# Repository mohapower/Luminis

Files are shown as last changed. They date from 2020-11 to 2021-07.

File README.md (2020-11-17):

# Luminis

**Fényerő kapcsolási határérték beállítása:**
1. Soros monitor megnyitása
  - Hardver csatlakoztatása usb kábbellel a számítógéphez
  - Arduino Ide megnyitása
  - Port beállítása: Menüsorvól: Eszközök/Port --> megfelelő port kiválasztása
  - Soros Monitor megnyitása: Eszközök/Soros monitor vagy Ctrl+Shift+M
  - Jobb alsó sarokban a "nincs sorvég" és "9600 baud" legyen beállítva
  - Ha minden működik, akkor a következő adatok jelennek meg másodpercenként:
    - Mert fenyero: 158
    - A beallitott kapcsolasi hatarartek: 333
    - Sotet van/Világos van
    
2. Fényerő kapcsolási határérték beállítása:
  - Bal felső beviteli mezőbe írjuk be az új kapcsolási határértéket, 0-1023 közötti értékek megfelelőek
  - Nomjuk meg a külség gombot (enter), a következő jelenik meg:
    - Az uj kapcsolasi hatarertek: 777
    - Mert fenyero: 232
    - A beallitott kapcsolasi hatarartek: 777
    - Sotet van

Amennyiben a mert fényerő alacsonyabb mit a beállított, az eszköt azt érzékeli, hogy sötét van. Vagyis ha a kapcsolási határértéket növeljük, a világítás előbb (nagyobb fénynél) fog kapcsolni.

**Firmware frissítés:**
Open your sketch
Open the IdoRele.ino

Select your board type and port
Select Tools > Board > Arduino AVR Boards > Arduino Nano.

NOTE: We have updated the Nano board with a fresh bootloader. 
Boards sold by us from January 2018 have this new bootloader, while boards manufactured before that date have the old bootloader. 
First, check that Tools > Board > Boards Manager shows you have the Arduino AVR Boards 1.16.21 or later installed. 
Then, to program the NEW Arduino NANO boards you need to chose Tools > Processor > ATmega328P. 
To program old boards you need to choose Tools > Processor > ATmega328P (Old Bootloader). 
If you get an error while uploading or you are not sure which bootloader you have, try each Tools > Processor menu option until your board gets properly programmed.

Upload and Run your first Sketch
To upload the sketch to the Arduino Nano, click the Upload button in the upper left to load and run the sketch on your board:

UNO Upload

Wait a few seconds - you should see the RX and TX LEDs on the board flashing. 
If the upload is successful, the message "Done uploading." will appear in the status bar.

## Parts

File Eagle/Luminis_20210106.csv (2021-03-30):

Qty | Value | Device | Package | Parts | Description | MF | MPN | OC_FARNELL | OC_NEWARK | SPICEPREFIX
1 |  | ARDUINO_NANO | ARDUINO_NANO | ARDUINO_NANO_V3 | Arduino Nano V3.0
1 | 100n | C-EUC1206 | C1206 | C2 | CAPACITOR, European symbol |  |  |  |  | C
1 | 330n | C-EUC1206 | C1206 | C1 | CAPACITOR, European symbol |  |  |  |  | C
1 | 7808DT | 7808DT | TO252 | IC1 | Positive VOLTAGE REGULATOR |  |  | DPAC
1 | ES1B | DIODE-DO214AC | DO214AC | D1 | DIODE |  |  | SMA
10 | MKDSN1,5/2-5,08 | MKDSN1,5/2-5,08 | MKDSN1,5/2-5,08 | IN, PWR, X1 | MKDSN 1,5/ 2-5,08 Printklemme
1 | SMBJ24CD-M3/H | SUPPRESSOR-SMBJ | SMBJ | D2 | Suppressor diode
1 | TR5, 0,5A | TR5 | TR5 | F1 | FUSE |  |  | unknown | unknown
1 | SEN0043 DFROBOT

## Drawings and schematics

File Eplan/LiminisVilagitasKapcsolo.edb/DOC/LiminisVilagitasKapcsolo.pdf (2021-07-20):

## Folyosó világítás működtető jel Másik Időrelétől (D7 pin)

-U3

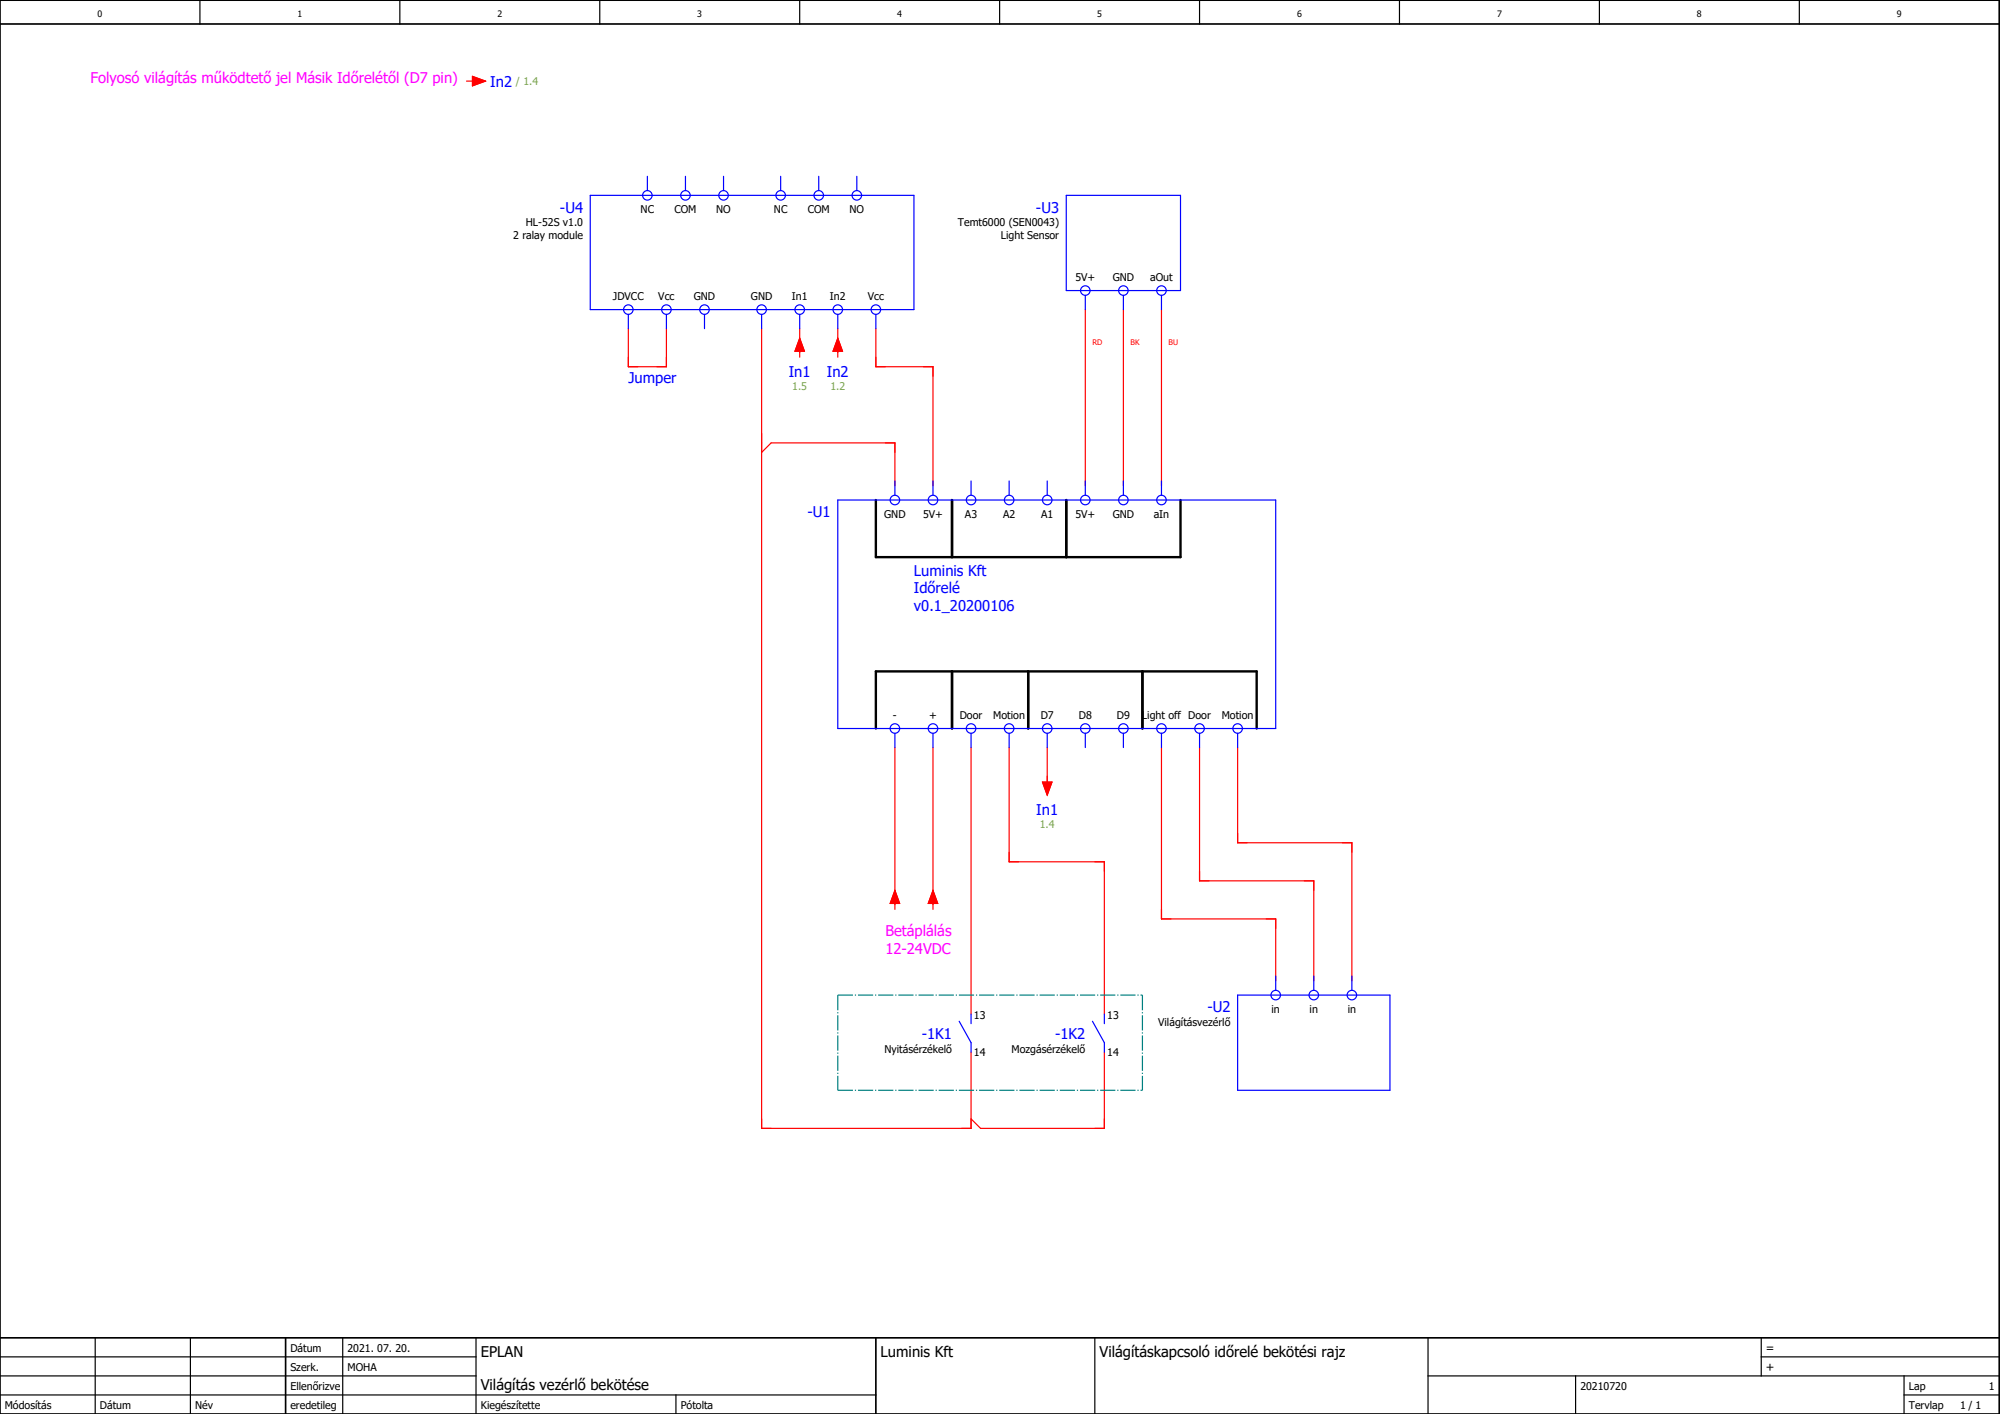
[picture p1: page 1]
Luminis Kft Időrelé v0.1_20200106; Jumper; Betáplálás 12-24VDC; GND; aIn; Door Motion; Light off Door Motion; Nyitásérzékelő; Mozgásérzékelő; Világításvezérlő; Temt6000 (SEN0043) Light Sensor; aOut; HL-52S v1.0 2 ralay module; JDVCC; Vcc; COM

Dátum | 2021. 07. 20. | EPLAN Világítás vezérlő bekötése | Luminis Kft | Világításkapcsoló időrelé bekötési rajz | =
Szerk. | MOHA | | | | +

Ellenőrizve | | | | | 20210720 | Lap 1

Módosítás | Dátum | Név | eredetileg | | Kiegészítette | Pótolta | | | | Tervlap 1 / 1

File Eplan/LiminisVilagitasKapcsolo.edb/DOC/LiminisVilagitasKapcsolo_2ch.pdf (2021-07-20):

-U3

-U4

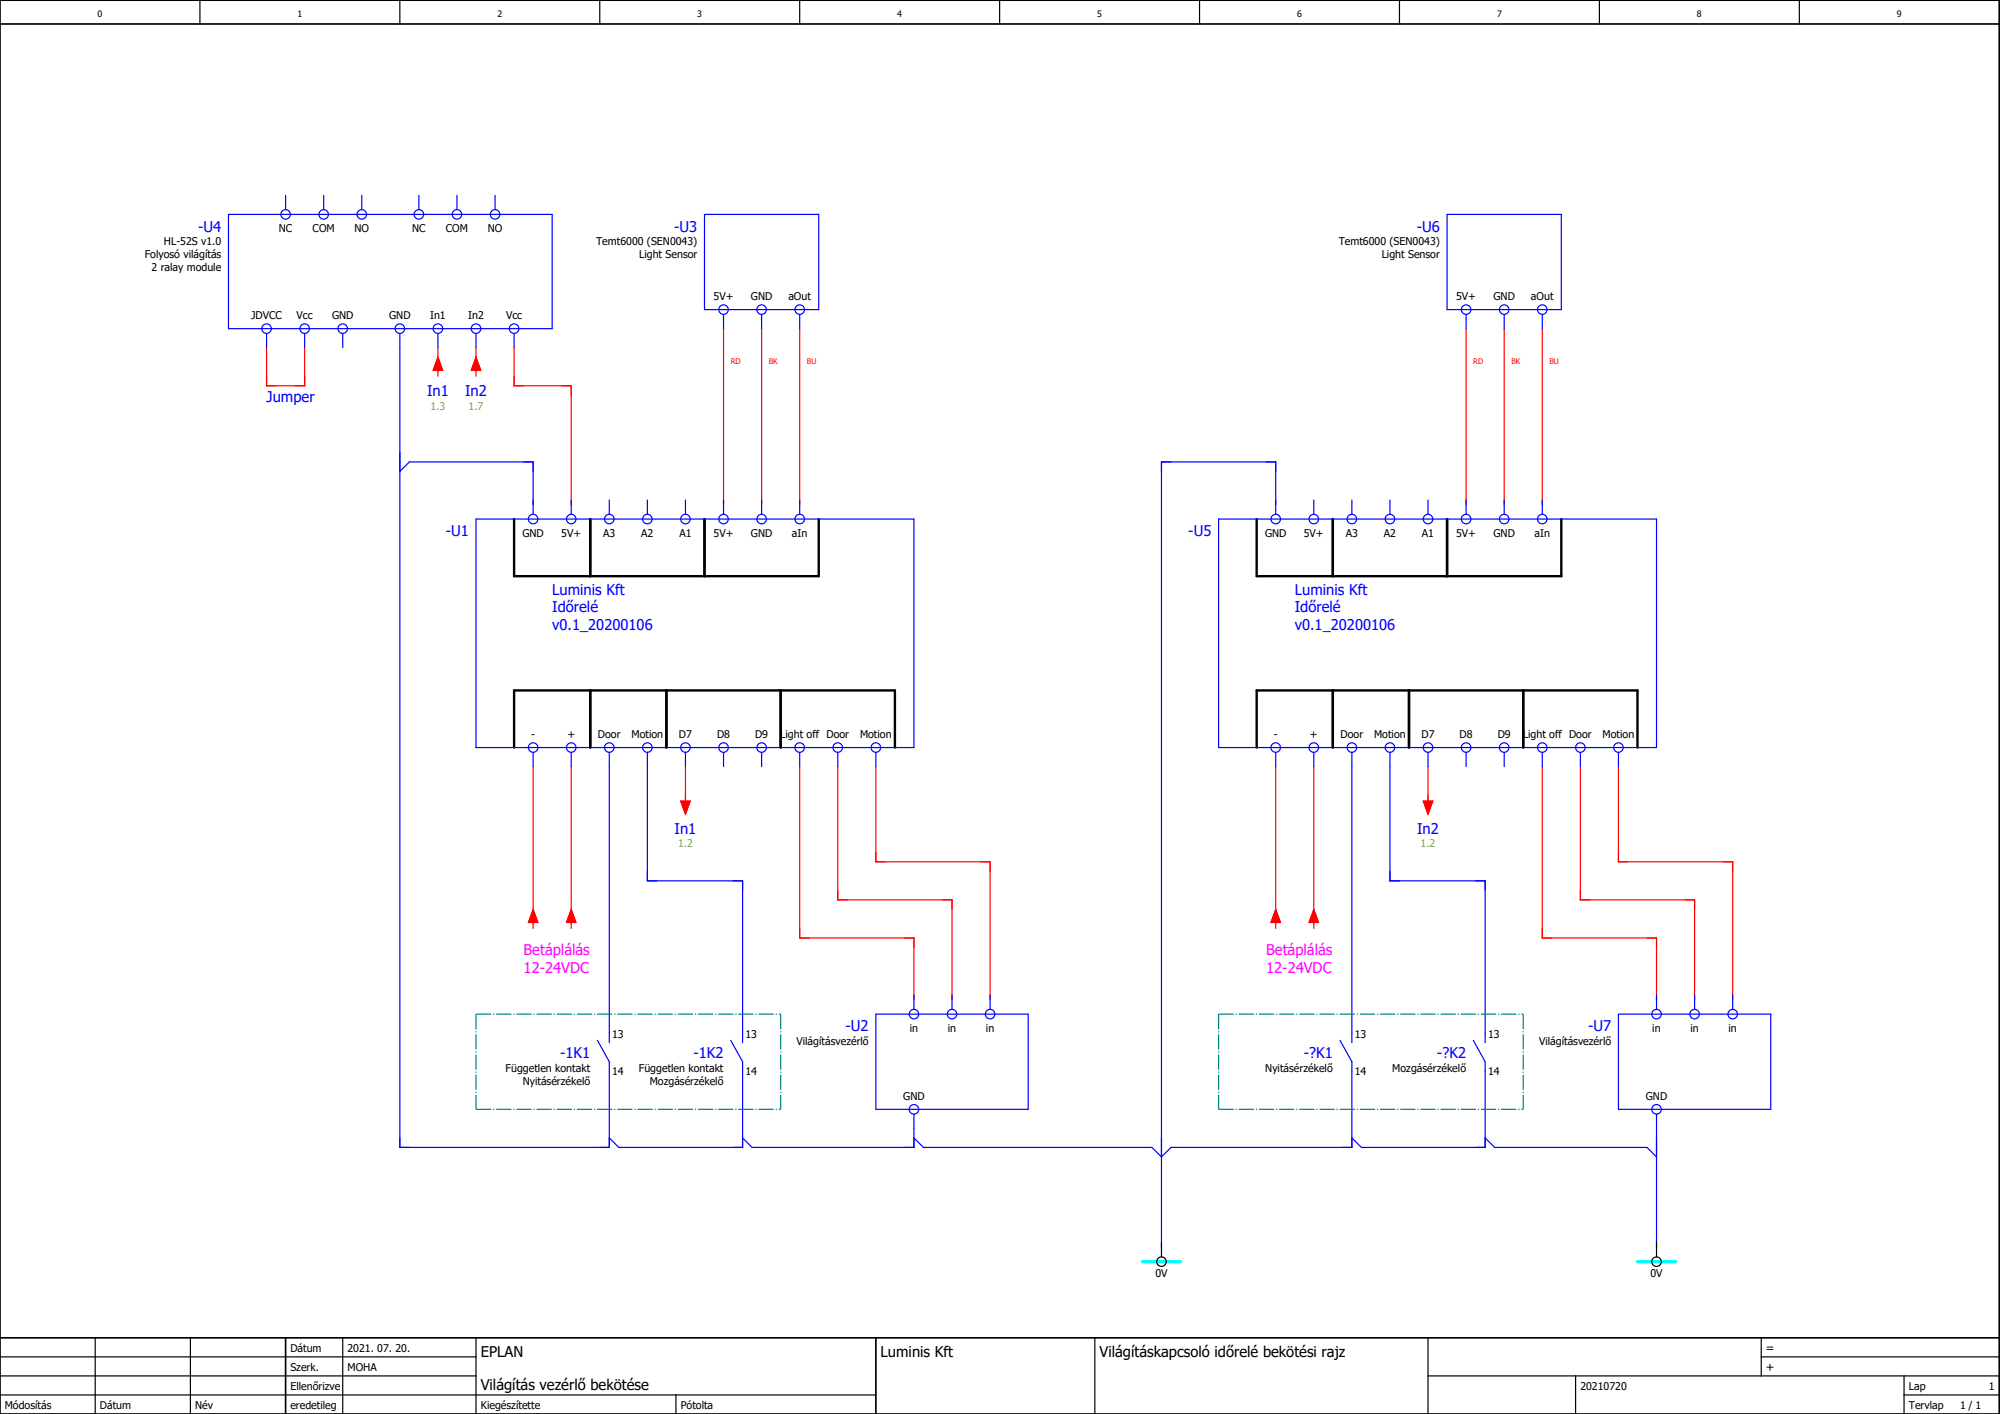
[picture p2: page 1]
Luminis Kft Időrelé v0.1_20200106; Jumper; Betáplálás 12-24VDC; GND; aIn; Door Motion; Light off Door Motion; Független kontakt Nyitásérzékelő; Független kontakt Mozgásérzékelő; Világításvezérlő; Temt6000 (SEN0043) Light Sensor; aOut; HL-52S v1.0 Folyosó világítás 2 ralay module; JDVCC; Vcc; COM; Nyitásérzékelő; Mozgásérzékelő

Dátum | 2021. 07. 20. | EPLAN Világítás vezérlő bekötése | Luminis Kft | Világításkapcsoló időrelé bekötési rajz | =
Szerk. | MOHA | | | | +

Ellenőrizve | | | | | 20210720 | Lap 1

Módosítás | Dátum | Név | eredetileg | | Kiegészítette | Pótolta | | | | Tervlap 1 / 1

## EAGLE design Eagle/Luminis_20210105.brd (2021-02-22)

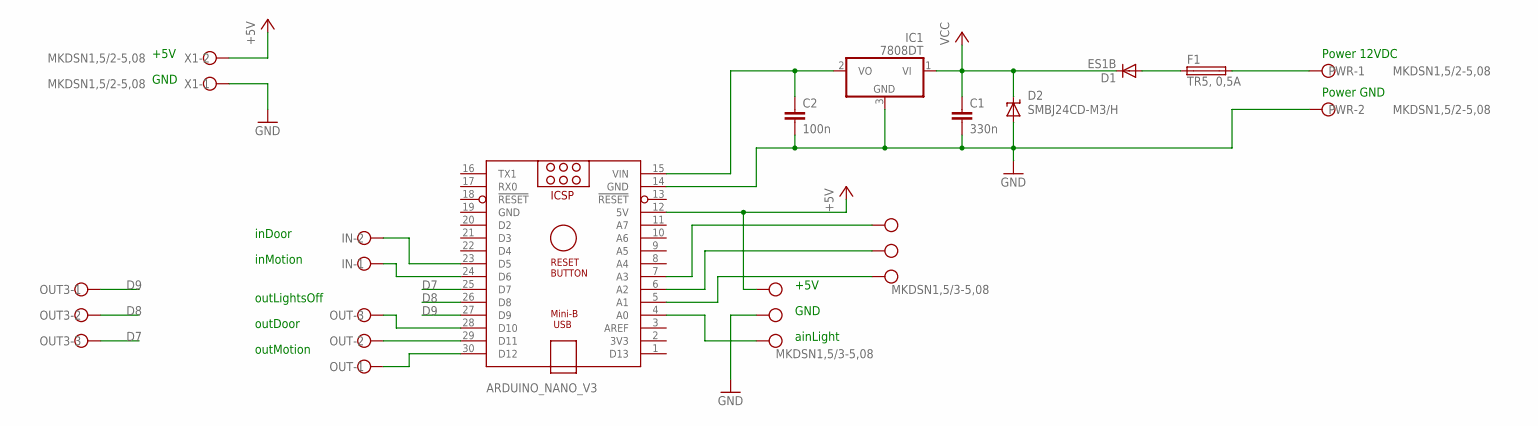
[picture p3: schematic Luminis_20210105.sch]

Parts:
ARDUINO_NANO_V3: ARDUINO_NANO
C1: 330n; C1206
C2: 100n; C1206
D1: ES1B; DO214AC
D2: SMBJ24CD-M3/H; SMBJ
F1: TR5, 0,5A; TR5
IC1: 7808DT; TO252
IN: MKDSN1,5/2-5,08
OUT, OUT1, OUT2, OUT3: MKDSN1,5/3-5,08
PWR: MKDSN1,5/2-5,08
X1: MKDSN1,5/2-5,08

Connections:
+5V: ARDUINO_NANO_V3.12 (5V), OUT1.1, X1.2
D7: ARDUINO_NANO_V3.25 (D7), OUT3.3
D8: ARDUINO_NANO_V3.26 (D8), OUT3.2
D9: ARDUINO_NANO_V3.27 (D9), OUT3.1
GND: ARDUINO_NANO_V3.14 (GND), ARDUINO_NANO_V3.19 (GND), C1.2, C2.2, D2.A, IC1.3 (GND), OUT1.2, PWR.2, X1.1
unnamed: ARDUINO_NANO_V3.4 (A0), OUT1.3
unnamed: ARDUINO_NANO_V3.5 (A1), OUT2.3
unnamed: ARDUINO_NANO_V3.30 (D12), OUT.1
unnamed: ARDUINO_NANO_V3.6 (A2), OUT2.2
unnamed: F1.2, PWR.1
unnamed: ARDUINO_NANO_V3.29 (D11), OUT.2
unnamed: ARDUINO_NANO_V3.28 (D10), OUT.3
unnamed: ARDUINO_NANO_V3.7 (A3), OUT2.1
unnamed: ARDUINO_NANO_V3.24 (D6), IN.1
unnamed: ARDUINO_NANO_V3.23 (D5), IN.2
unnamed: D1.A, F1.1
unnamed: ARDUINO_NANO_V3.15 (VIN), C2.1, IC1.2 (VO)
VCC: C1.1, D1.C, D2.C, IC1.1 (VI)

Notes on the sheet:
Power 12VDC
Power GND
outLightsOff
outMotion
outDoor
inDoor
inMotion
ainLight
GND
+5V

Board: 2 copper layers, 14 parts (0 on the bottom side), 18 nets, no tracks yet.

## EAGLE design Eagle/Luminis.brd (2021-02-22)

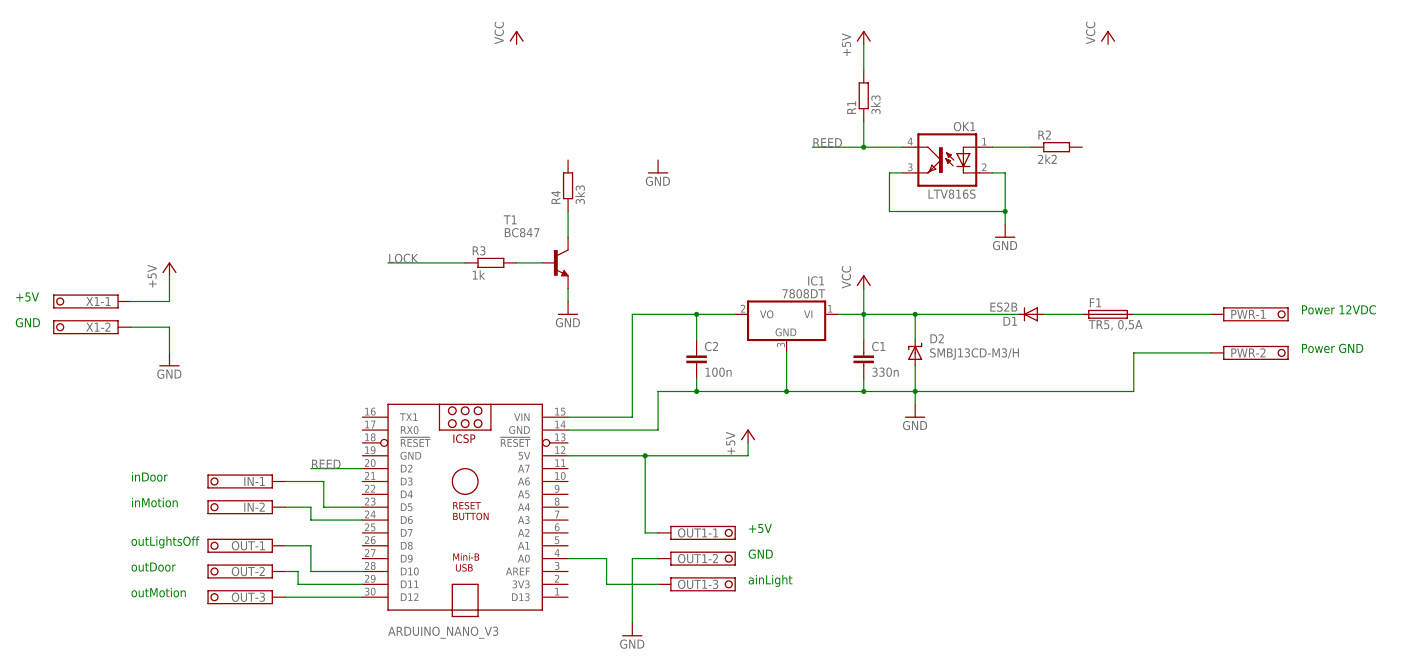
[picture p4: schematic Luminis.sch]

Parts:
ARDUINO_NANO_V3: ARDUINO_NANO
C1: 330n; C1206
C2: 100n; C1206
D1: ES2B; SMB
D2: SMBJ13CD-M3/H; SMBJ
F1: TR5, 0,5A; TR5
IC1: 7808DT; TO252
IN: 1751248
OK1: LTV816S; DIL4-SMD
OUT, OUT1: 1751251
PWR: 1751248
R1, R4: 3k3; R1206
R2: 2k2; R1206
R3: 1k; R1206
T1: BC847; SOT23
X1: 1751248

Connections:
+5V: ARDUINO_NANO_V3.12 (5V), OUT1.1, R1.2, X1.1
GND: ARDUINO_NANO_V3.14 (GND), ARDUINO_NANO_V3.19 (GND), C1.2, C2.2, D2.A, IC1.3 (GND), OK1.2 (C), OK1.3 (EMIT), OUT1.2, PWR.2, T1.2 (E), X1.2
LOCK: R3.1
unnamed: ARDUINO_NANO_V3.4 (A0), OUT1.3
unnamed: OK1.1 (A), R2.1
unnamed: ARDUINO_NANO_V3.30 (D12), OUT.3
unnamed: R4.1, T1.3 (C)
unnamed: F1.2, PWR.1
unnamed: ARDUINO_NANO_V3.29 (D11), OUT.2
unnamed: ARDUINO_NANO_V3.28 (D10), OUT.1
unnamed: ARDUINO_NANO_V3.24 (D6), IN.2
unnamed: ARDUINO_NANO_V3.23 (D5), IN.1
unnamed: R3.2, T1.1 (B)
unnamed: D1.A, F1.1
unnamed: ARDUINO_NANO_V3.15 (VIN), C2.1, IC1.2 (VO)
REED: ARDUINO_NANO_V3.20 (D2), OK1.4 (COL), R1.1
VCC: C1.1, D1.C, D2.C, IC1.1 (VI)

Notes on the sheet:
Power 12VDC
Power GND
outLightsOff
outMotion
outDoor
inDoor
inMotion
ainLight
GND
+5V

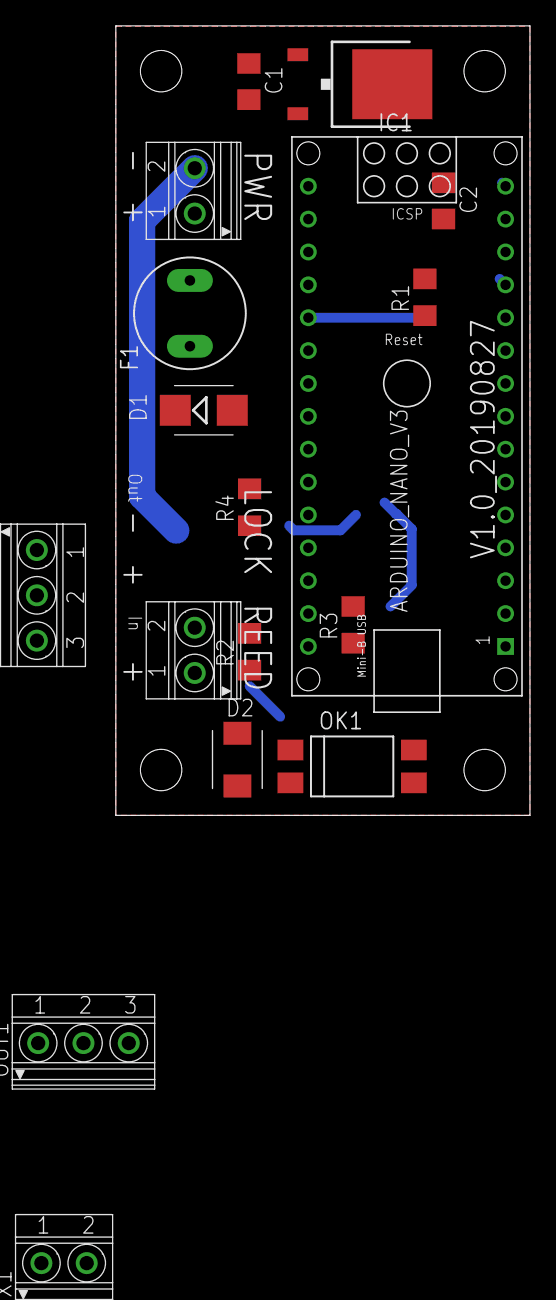
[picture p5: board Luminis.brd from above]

Board: 2 copper layers, 32.0 x 61.0 mm, 18 parts (1 on the bottom side), 16 nets.

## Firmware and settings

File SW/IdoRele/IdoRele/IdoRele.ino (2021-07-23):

#include <EEPROM.h>
//const long interval = 5000; //ennyit kesleltet (ms)
const long interval = 900000; //(15 Perc) ennyit kesleltet (ms)
//const long interval = 30000; //ennyit kesleltet (ms)

#define LIGHTSENSORPIN A0


const int ledPin = LED_BUILTIN;// the number of the LED pin
const int lightOffOut = 10;
const int ajtoOut = 11;
const int mozgasOut = 12;
const int releOut = 7;

const int ajtoIn = 5; // the number of the LED pin
const int mozgasIn = 6; // the number of the LED pin

const long interval2 = 1000;
unsigned long previousMillis = 0; 
unsigned long previousMillis2 = 0;        

unsigned int data = 0;
bool outputFlag = false;
bool input1Last = false;
bool input2Last = false;
bool vilagosVan = true;

bool valtasFlag1 = false;
bool valtasFlag2 = false;
int kapcsolasiSzint = 0;
int hiszterezis=10;

int smooth(){
  int i;
  int value = 0;
  int numReadings = 20;

  for (i = 0; i < numReadings; i++){
    // Read light sensor data.
    value = value + analogRead(LIGHTSENSORPIN);

    // 1ms pause adds more stability between reads.
    delay(1);
  }

  // Take an average of all the readings.
  value = value / numReadings;

  return value;
}

void writeUnsignedIntIntoEEPROM(int address, unsigned int number)
{
	EEPROM.write(address, number >> 8);
	EEPROM.write(address + 1, number & 0xFF);
}

unsigned int readUnsignedIntFromEEPROM(int address)
{
	return (EEPROM.read(address) << 8) + EEPROM.read(address + 1);
}


void setup() {
	Serial.begin(9600);
	// set the digital pin as output:
	pinMode(ledPin, OUTPUT);
	pinMode(lightOffOut, OUTPUT);
	pinMode(ajtoOut, OUTPUT);
	pinMode(mozgasOut, OUTPUT);
	pinMode(releOut, OUTPUT);
	digitalWrite(releOut, HIGH);
	pinMode(ajtoIn, INPUT_PULLUP);
	pinMode(mozgasIn, INPUT_PULLUP);
	pinMode(LIGHTSENSORPIN,  INPUT);  


	kapcsolasiSzint = readUnsignedIntFromEEPROM(0);
	Serial.print("Az uj kapcsolasi hatarertek: ");
	Serial.println(kapcsolasiSzint);

}

void loop() {
	//Serial.println(millis());
	//delay(1000);
int sensorValue= smooth();
unsigned long currentMillis = millis();
unsigned long currentMillis2 = millis();

if (currentMillis2 - previousMillis2 >= interval2){
	previousMillis2 = currentMillis2;

	
  	Serial.print("Mert fenyero: ");
  	Serial.println(sensorValue);

	Serial.print("A beallitott hatarartek: ");
  	Serial.println(kapcsolasiSzint);

	if(vilagosVan){
		Serial.println("Vilagos van");
	}
	else
	{
		Serial.println("Sotet van");
	}
	Serial.println("");
}

	if(Serial.available() > 0){
		data = Serial.parseInt();
		if (0 < data && data < 1024) {
			writeUnsignedIntIntoEEPROM(0, data);
			kapcsolasiSzint = readUnsignedIntFromEEPROM(0);
			Serial.print("Az uj kapcsolasi hatarertek: ");
			Serial.println(kapcsolasiSzint);
		}
		else
		{
			Serial.println("Ervenytelen adat");
		}
	}
	

	

	



//Ha vilagos van nem tovabbitjuk az ajto es a mozgas jelet, es lekapcsoljuk a villanyt
	if(sensorValue>(kapcsolasiSzint+hiszterezis) && vilagosVan==false){
		vilagosVan=true;
		digitalWrite(releOut, HIGH);
		digitalWrite(ledPin, HIGH);
			digitalWrite(lightOffOut, HIGH);
			delay(1000);
			digitalWrite(ledPin, LOW);
			digitalWrite(lightOffOut, LOW);
			outputFlag = true;
		
	}
	else if(sensorValue<(kapcsolasiSzint-hiszterezis) && vilagosVan==true ){
		vilagosVan=false;
		
	}

//Ha sotet van es van mozgas, mukodtetjuk a vilagitast- Egeszen addig vilagit, mig mozgas van. + 15 perc
	if(!vilagosVan){	
	
			//Az ajto es a mozgas kimeneteket a bemenetekkel megegyezo szintre allitjuk
		if (!digitalRead(ajtoIn)) {
			digitalWrite(ajtoOut, HIGH);
		}
		else
		{
			digitalWrite(ajtoOut, LOW);
		}

		if (!digitalRead(mozgasIn)) {
			digitalWrite(mozgasOut, HIGH);
		}
		else {
			digitalWrite(mozgasOut, LOW);
		}
		
		//ajto valtozas figyeles
		if (digitalRead(ajtoIn) != input1Last) {
			input1Last = digitalRead(ajtoIn);
			valtasFlag1 = true;
		}
		else {
			valtasFlag1 = false;
		}
		//mozgas figyeles
		if (digitalRead(mozgasIn) != input2Last) {
			input2Last = digitalRead(mozgasIn);
			valtasFlag2 = true;
		}
		else {
			valtasFlag2 = false;
		}

		//Ha mozgas vagy ajtonyitas van, nullazzuk az idozitot
		if (valtasFlag1 || !digitalRead(mozgasIn)) {
			digitalWrite(releOut, LOW);
			previousMillis = currentMillis;
			outputFlag = false;
		}
		//Ha letelt az idozites, lekapcsoljuk a vilagitast
		if ((currentMillis - previousMillis >= interval) && !outputFlag) {	
			digitalWrite(releOut, HIGH);
			digitalWrite(ledPin, HIGH);
			digitalWrite(lightOffOut, HIGH);
			delay(1000);
			digitalWrite(ledPin, LOW);
			digitalWrite(lightOffOut, LOW);
			outputFlag = true;
		}
	}
	else
	{
		//ajto valtozas figyeles
		if (digitalRead(ajtoIn) != input1Last) {
			input1Last = digitalRead(ajtoIn);
			valtasFlag1 = true;
		}
		else {
			valtasFlag1 = false;
		}
		//mozgas figyeles
		if (digitalRead(mozgasIn) != input2Last) {
			input2Last = digitalRead(mozgasIn);
			valtasFlag2 = true;
		}
		else {
			valtasFlag2 = false;
		}

		//Ha mozgas vagy ajtonyitas van, nullazzuk az idozitot
		if (valtasFlag1 || !digitalRead(mozgasIn)) {
			previousMillis = currentMillis;
			outputFlag = false;
		}
		//Ha letelt az idozites, lekapcsoljuk a vilagitast
		if ((currentMillis - previousMillis >= interval) && !outputFlag) {
			digitalWrite(ledPin, HIGH);
			digitalWrite(lightOffOut, HIGH);
			delay(1000);
			digitalWrite(ledPin, LOW);
			digitalWrite(lightOffOut, LOW);
			outputFlag = true;
		}
	}
	
	
}

/*#include <EEPROM.h>

//const long interval = 900000; //ennyit kesleltet (ms)
#define LIGHTSENSORPIN A0


const int ledPin = LED_BUILTIN;// the number of the LED pin
const int lightOffOut = 10;
const int ajtoOut = 11;
const int mozgasOut = 12;

const int ajtoIn = 5; // the number of the LED pin
const int mozgasIn = 6; // the number of the LED pin


const long interval2 = 1000;
unsigned long previousMillis = 0; 
unsigned long previousMillis2 = 0;       

unsigned int data = 0;
bool outputFlag = false;
bool input1Last = false;
bool input2Last = false;
bool vilagosVan = true;

bool valtasFlag1 = false;
bool valtasFlag2 = false;
int kapcsolasiSzint = 0;
int hiszterezis=10;

int smooth(){
  int i;
  int value = 0;
  int numReadings = 10;

  for (i = 0; i < numReadings; i++){
    // Read light sensor data.
    value = value + analogRead(LIGHTSENSORPIN);

    // 1ms pause adds more stability between reads.
    delay(1);
  }

  // Take an average of all the readings.
  value = value / numReadings;

  return value;
}

void writeUnsignedIntIntoEEPROM(int address, unsigned int number)
{
  EEPROM.write(address, number >> 8);
  EEPROM.write(address + 1, number & 0xFF);
}

unsigned int readUnsignedIntFromEEPROM(int address)
{
  return (EEPROM.read(address) << 8) + EEPROM.read(address + 1);
}


void setup() {
  Serial.begin(9600);
  // set the digital pin as output:
  pinMode(ledPin, OUTPUT);
  pinMode(lightOffOut, OUTPUT);
  pinMode(ajtoOut, OUTPUT);
  pinMode(mozgasOut, OUTPUT);
  pinMode(ajtoIn, INPUT_PULLUP);
  pinMode(mozgasIn, INPUT_PULLUP);
  pinMode(LIGHTSENSORPIN,  INPUT);  

  kapcsolasiSzint = readUnsignedIntFromEEPROM(0);
  Serial.print("Az uj kapcsolasi hatarertek: ");
  Serial.println(kapcsolasiSzint);

}

void loop() {
  //Serial.println(millis());
  //delay(1000);
  int sensorValue= smooth();
  


  if(Serial.available() > 0){
    data = Serial.parseInt();
    if (0 < data && data < 1024) {
      writeUnsignedIntIntoEEPROM(0, data);
      kapcsolasiSzint = readUnsignedIntFromEEPROM(0);
      Serial.print("Az uj kapcsolasi hatarertek: ");
      Serial.println(kapcsolasiSzint);
    }
    else
    {
      Serial.println("Ervenytelen adat");
    }
  }
  

  unsigned long currentMillis = millis();
  unsigned long currentMillis2 = millis();
  //int value = digitalRead(ajtoIn);
if (currentMillis2 - previousMillis2 >= interval2){
  previousMillis2 = currentMillis2;
  Serial.print("fenyero: ");
  Serial.println(sensorValue);
}

  



//Ha vilagos van nem tovabbitjuk az ajto es a mozgas jelet, es lekapcsoljuk a villanyt
  if(sensorValue>(kapcsolasiSzint+hiszterezis) && vilagosVan==false && outputFlag==true){
    vilagosVan=true;
    
  }
  else if(sensorValue<(kapcsolasiSzint-hiszterezis) && vilagosVan==true && outputFlag==true){
    vilagosVan=false;
    
  }

//Ha sotet van es van mozgas, mukodtetjuk a vilagitast- Egeszen addig vilagit, mig mozgas van. + 15 perc
  if(!vilagosVan){  
  
      //Az ajto es a mozgas kimeneteket a bemenetekkel megegyezo szintre allitjuk
    if (!digitalRead(ajtoIn)) {
      digitalWrite(ajtoOut, HIGH);
    }
    else
    {
      digitalWrite(ajtoOut, LOW);
    }

    if (!digitalRead(mozgasIn)) {
      digitalWrite(mozgasOut, HIGH);
    }
    else {
      digitalWrite(mozgasOut, LOW);
    }
    
    //ajto valtozas figyeles
    if (digitalRead(ajtoIn) != input1Last) {
      input1Last = digitalRead(ajtoIn);
      valtasFlag1 = true;
    }
    else {
      valtasFlag1 = false;
    }
    //mozgas figyeles
    if (digitalRead(mozgasIn) != input2Last) {
      input2Last = digitalRead(mozgasIn);
      valtasFlag2 = true;
    }
    else {
      valtasFlag2 = false;
    }

    //Ha mozgas vagy ajtonyitas van, nullazzuk az idozitot
    if (valtasFlag1 || !digitalRead(mozgasIn)) {
      previousMillis = currentMillis;
      outputFlag = false;
    }
    //Ha letelt az idozites, lekapcsoljuk a vilagitast
    if ((currentMillis - previousMillis >= interval) && !outputFlag) {    
      digitalWrite(ledPin, HIGH);
      digitalWrite(lightOffOut, HIGH);
      delay(1000);
      digitalWrite(ledPin, LOW);
      digitalWrite(lightOffOut, LOW);
      outputFlag = true;
    }
  }
  
  
}
*/

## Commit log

2020-11-10 Add project files
    [IdoRele.xlsx]
2020-11-10 Update Docs
    [IdoRele.xlsx]
2021-03-30 Add BOM
    [Luminis_20210106.csv]
2021-07-20 - add eplan project - add corridor light relay
